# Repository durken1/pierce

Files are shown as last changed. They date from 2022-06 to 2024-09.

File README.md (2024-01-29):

# pierce 2.0

pierce  

pierce 2.0 is a split modular wireless / semi-wireless 36 key column staggered keyboard. The design is inspired by [Corne](https://github.com/foostan/crkbd) with more pinky stagger as well as only using 1u keycaps.
It is possible to build a wireless version or a semi wireless version. If building the wireless version an additional reciever dongle is required. 
In the semi wireless version the wired half is also acting as a reciever for the wireless half.
Both versions have full [QMK support](https://github.com/qmk/qmk_firmware/tree/master/keyboards/pierce).  
Supported switches: MX, Choc V1, Alps

The semi wireless version has a built in reset circuit for connecting a PS/2 pointing device.

There are 3 different PCBs: wireless (reversible), wired (right) and reciever.

A programmer is necessary to flash the wireless modules. A cheap option is getting an ST-Link V2 clone from ebay.

# Bill of materials
## Wireless
| Qty | Item | Comments |
|----:|---|---|
| 2 | Pierce 2.0 wireless PCB | |
| 1 | Pierce 2.0 reciever PCB | |
| 1 | Pro micro or equivalent | |
| 2 | Keystone 3034 Coin cell battery retainer | SMD |
| 2 | 2032 3.3V Coin cell battery | |
| 3 | YJ-14015 / Core51822 (B) | |
| 3 | 1x4 pin Right-angle 2.54 mm header | For programming RF modulules. Optional, temporary soldered wires works fine|
| 2 | 4.7 kΩ resistor | SMD 1206 |
| 1 | 1117 3.3 V regulator | SMD SOT-223 |
| 1 | THT momentary switch | 2 pin THT 6 mm |
  
## Semi wireless
| Qty | Item | Comments |
|----:|---|---|
| 1 | Pierce 2.0 wireless PCB | |
| 1 | Pierce 2.0 wired PCB | |
| 1 | Pro micro or equivalent | Elite C recommended if using trackpoint. (Pin D5 broken out)|
| 1 | Keystone 3034 Coin cell battery retainer | SMD |
| 1 | 2032 3.3V Coin cell battery | |
| 2 | YJ-14015 / Core51822 (B) | |
| 2 | 1x4 pin Right-angle 2.54 mm header | For programming RF modulules. Optional, temporary soldered wires works fine|
| 2/4 | 4.7 kΩ resistor | SMD 1206, 4 if using trackpoint, otherwise 2 |
| 1 | 1117 3.3 V regulator | SMD SOT-223 |
| 1 | THT momentary switch | 2 pin THT 6 mm |
| 1 | 100 kΩ resistor | SMD 1206 Only for trackpoint |
| 1 | 2.2 uF capacitor | SMD 1206 Only for trackpoint |
| 1 | Trackpoint module | [R61](https://deskthority.net/wiki/TrackPoint_Hardware#ThinkPad_R61_TrackPoint) recommended, Only for.. well..|
  
# Build instructions
## Soldering

The soldering is pretty straight forward and it should be obvious what component goes where. If you haven't soldered SMD components before I recommend watching a youtube tutorial or two beforehand. I suggest adding a bit of solder to the middle pad for the battery holder.

## Flashing wireless modules

The following instructions is for using an ST-Link V2 clone and Windows.
1. Download and install OpenOCD from https://openocd.org/ and drivers for the programmer from https://www.st.com/en/development-tools/stsw-link009.html
2. Create a file called 'openocd.cfg' in the bin folder where you installed OpenOCD with the following content:

        #nRF51822 Target
        source [find interface/stlink-v2.cfg]

        transport select hla_swd

        set WORKAREASIZE 0x4000
        source [find target/nrf51.cfg]

3. Copy the relevant firmware .bin file to the bin folder where you installed OpenOCD
4. Connect the 4 pins SWCLK, SWDIO, GND and 3.3 V on the ST-Link V2 to the matching pad on the PCB and the ST-Link to the computer
5. Open a command prompt, navigate to the bin folder mentioned above and enter:

        openocd.exe -f openocd.cfg
        
6. Open another command prompt and enter:

        telnet localhost 4444
You should now be connected to the programmer. Enter the following commands to flash the firmware:

    halt
    nrf51 mass_erase
    program <firmware_file_name>.bin
    reset

That's it! You should now have a working pierce keyboard.

# Plates
## These need some work
I have included files to 3D print bottom plates and switch plates (only for alps for now). The idea of the screwless bottom plates is to use a friction fit, but I'm not sure how well the current version fits.

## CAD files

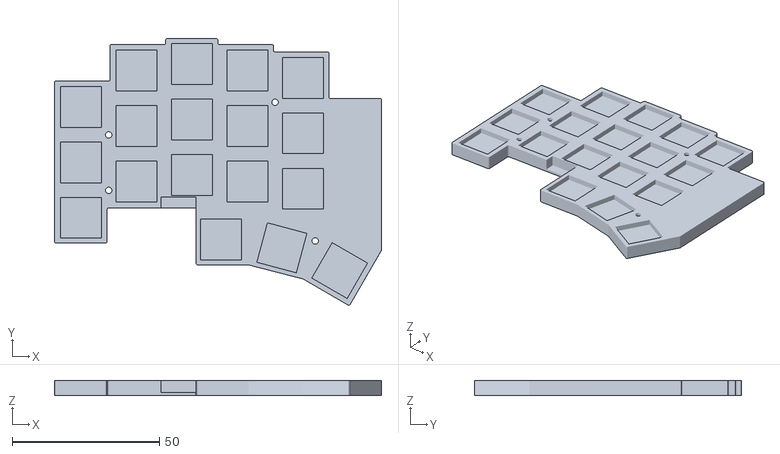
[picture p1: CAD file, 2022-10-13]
plates/Pierce MX Bottom Plate.stl
111.2 x 90.6 x 5.00

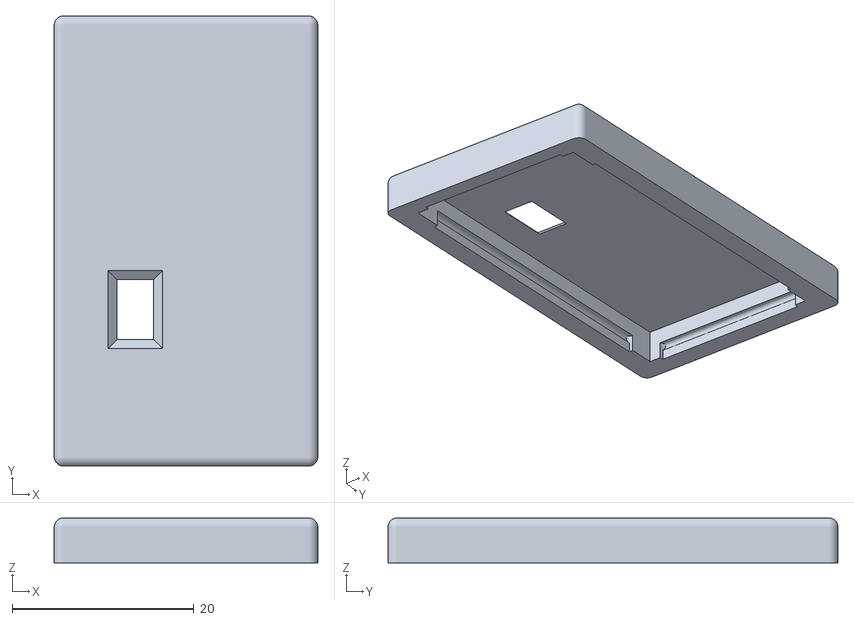
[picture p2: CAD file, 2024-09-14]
receiver_box/receiver_top.stl
29.0 x 49.5 x 4.95

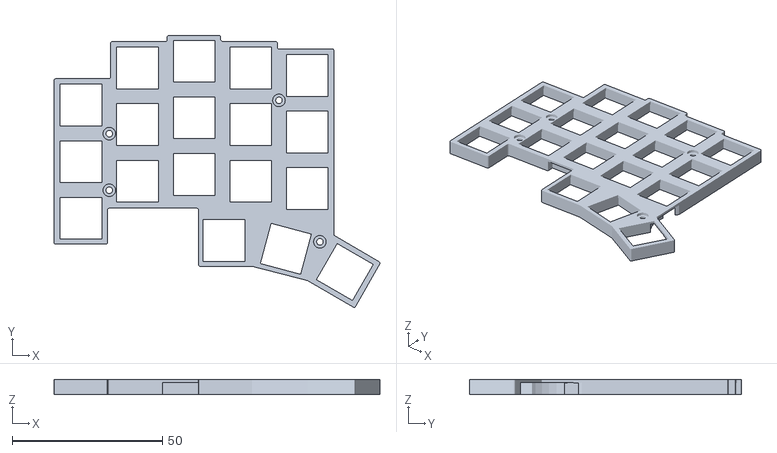
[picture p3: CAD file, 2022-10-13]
plates/Pierce MX Top Plate.stl
108.7 x 90.6 x 5.00

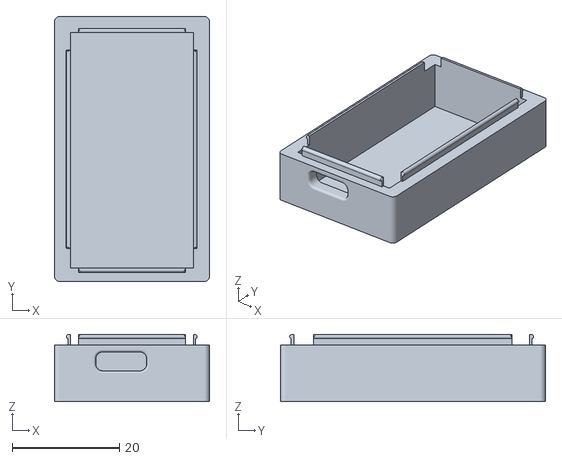
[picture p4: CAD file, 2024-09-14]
receiver_box/receiver_bottom.stl
29.0 x 49.5 x 12.6

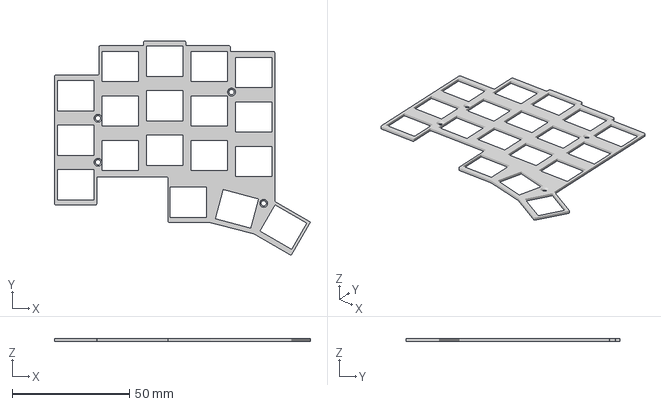
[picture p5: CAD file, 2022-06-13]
plates/alps_plate.3mf
109.3 x 91.4 x 1.20 mm

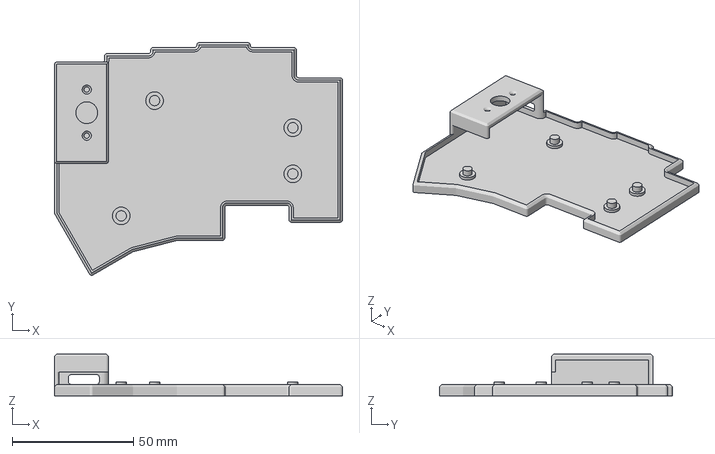
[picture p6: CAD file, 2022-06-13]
plates/wired_trackpoint_screwless.3mf
118.7 x 95.9 x 17.3 mm

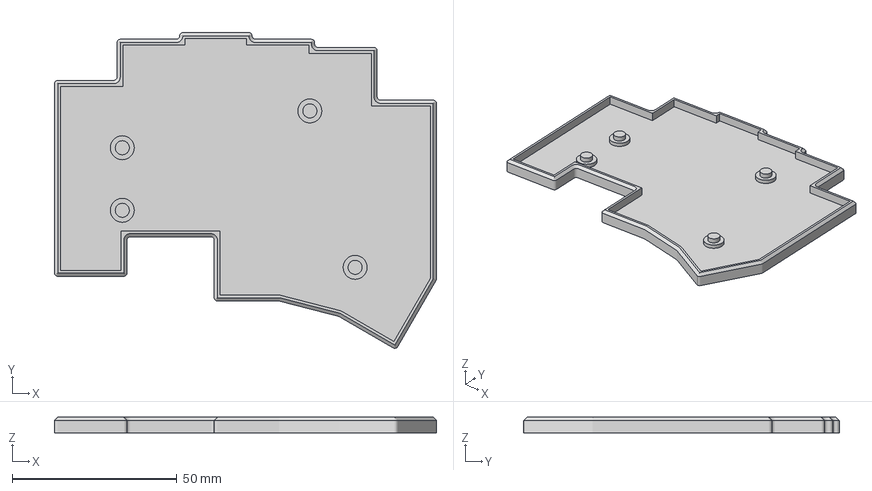
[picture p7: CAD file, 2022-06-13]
plates/wireless_bottom_screwless.3mf
116.0 x 95.9 x 4.80 mm

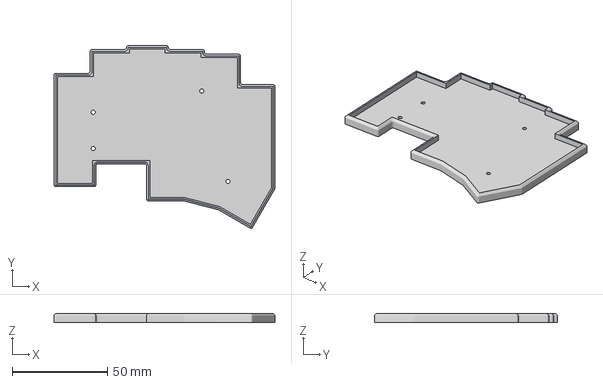
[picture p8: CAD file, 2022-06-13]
plates/wireless_bottom_screws.3mf
116.0 x 95.9 x 4.80 mm

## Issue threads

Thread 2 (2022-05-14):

Hello, good fellow.

azhizhinov, 2022-05-14:
Hello, good fellow.
Very interesting project.
Are these samples are completely functional?
Don't you mind if I've try to solder fully wireless one with dongle?
Thanks for your efforts.

durken1, 2022-05-14:
Hello,
You're very welcome to build it!
Everything is fully functional (I'm using this version as my daily driver).
I have a pending PR to the qmk main repo, but until it's approved you can get it here: https://github.com/durken1/qmk_firmware/tree/pierce/keyboards/pierce

azhizhinov, 2022-05-15:
Hello.
It seems, that you uses different case model for pierce 2.0.
Old cases looks too high.
Do you have some plans to release new case models?
Thanks in advance.

durken1, 2022-05-15:
Yes, that's true, the old case won't fit. I have made some simple bottom plates that I use. I'll add the STLs when I get the chance.

durken1, 2022-05-21:
Nice, if you decide to try them let me know how they work and I can add them to the repo.
I added the plates that I use. The screwless uses friction fit to attach the pcbs for a plateless build. The margins at the mounting points are quite small, so dependig on the printer it migh work better or worse.

azhizhinov, 2022-05-21:
Hello.
Thanks a lot.
For how long CR2032 will provide enough power for a half with daily usage?
At what distance from the halves does the receiver still provide stable communication?

durken1, 2022-05-21:
It's a bit difficult to say. They should last for almost 1000 hours of active typing and with current firmware they go to deep sleep after 0.5 seconds. So it kinda depends on how much you type during daily usage. But to give an estimate, I used the prototype for about 9 months before having to change the battery.

I have tried them from about 3 meters away and through a door without issue. I can do some more testing to find out how far before they fail if you're interested.

azhizhinov, 2022-05-21:
Cool. This information is enough for.
Good results.

azhizhinov, 2022-05-23:
Hello.
Please, advice, how can I mirror wireless_bottom_screwless.3mf?
It's for left the half, right?
How the same model can be printed for the left half?
A 3D printer can mange such situation?
Thanks in advance.

durken1, 2022-05-23:
Yes, it's the left half. It can easily be mirrored in the slicing software before printing.

azhizhinov, 2022-05-23:
Is it not planned to use the top plate for Cherries, as for Alps?
Are the Cherries stable enough without the top plate?

durken1, 2022-05-23:
I will make a top plate for MX switches as well. At the moment I don't have much time though, but it's coming :). If the switches are 5 pin you don't have to have a top plate. If they are 3 pin you need a plate. You can see the difference here: https://m.media-amazon.com/images/I/61kURKmWOvL._AC_SL400_.jpg

azhizhinov, 2022-05-23:
Yep, time is always passing by.
Ok, I see, mine are 3-pin.
I think alps_plate.3mf can be used as well.
The Alps are for 15x14 mm cuts, the Cherries are for 14x14 cuts, centers of switches are the same, I think.
But borders of the bottom plate should be higher then, to hide the PCB itself and the top plate under.

azhizhinov, 2022-06-12:
Hello.
Do you have the case parts in .STL format?
It's more comfortable for editing with some free tools like FreeCAD.
Will be great to adopt this kind of bottom plate to Pierce, how do you think?
https://github.com/mattdibi/redox-keyboard/blob/master/redox-w/rev2.0WHS/case/BackplateL.stl
https://github.com/mattdibi/redox-keyboard/blob/master/redox-w/rev2.0WHS/case/OpenBackplateL.stl

durken1, 2022-06-14:
Hi!

I can export the case parts to STL when I get home from work today.
Regarding the other type of bottom plates, that's not really something I would find useful, but if you want to make them I'm happy to include them in the repo.

azhizhinov, 2022-06-19:
Hello.
There is some automation for cases.
May be you'll find this interesting.
https://github.com/Lenbok/scad-keyboard-cases

azhizhinov, 2022-06-29:
Hello.
An idea for the case, maybe that style already used in some projects, I don't know.
To fasten the switch plate with the bottom plate through the PCB.
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

durken1, 2022-06-30:
Hello.
You can find the hole on the pcb using kicad (pcbnew).
Regarding the mounting I guess it should work, but personally i prefer solutions that you can disassemble more easily. But let me know if you try it out and how it works!

And nice to see you flashed the dongle successfully :) please keep me updated on your build.

azhizhinov, 2022-06-30:
Hello.
Yep, I get to this point with the same conclusion. It's better to have possibility to disassemble a keyboard.
I've studied a lot of videos and now have better understanding of  KiCAD -> Blender process.
Sure will update, next step is to solder one of the halves and test with dongle.

azhizhinov, 2022-07-02:
Hello.
That was my first challenge with Blender.
So, here the result.
Could you, please check?
Do you have possibility to print these plates?
[20220702.DURKEN1.PIERCE.00.zip](https://github.com/durken1/pierce/files/9033579/20220702.DURKEN1.PIERCE.00.zip)

azhizhinov, 2022-08-21:
Hello.
I'm finished.
Now time for keymap/layers. :-)
Have you any plans for VIA/VIAL support?
Thanks in advance.
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

durken1, 2022-08-22:
Looks good! How do you like it?

No plans for via/vial support at the moment. Feel free to add it and make a PR though :)

durken1, 2022-09-06:
Are the plates working as intended? If so, would you mind adding them to the plates-folder with a PR? :)

azhizhinov, 2022-10-03:
> Are the plates working as intended? If so, would you mind adding them to the plates-folder with a PR? :)

Hello.
I've made the PR for plates.
And for via support also.
Have a nice day.

azhizhinov, 2023-03-24:
Hello.
Pierce now has support from VIA.
https://github.com/the-via/keyboards/pull/1747
Stay safe.

durken1, 2023-03-24:
Hello,
Nice! Thank you for your contribution!

Closed 2023-01-06.

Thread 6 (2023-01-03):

Flesh out build guide

chewiedies, 2023-01-03:
I am having a lot of trouble flashing the wireless modules. The instructions in the build guide are quite sparse and seem to make a lot of assumptions. Can you write up a more robust build guide with regards to firmware flashing and wireless module flashing?

azhizhinov, 2023-01-03:
Hello.
Sorry for shameless intervene.
I've flashed at least 12 modules.
It's easy with ST-Link and openocd.
Just need a Linux installation with openocd.
You have to connect a wireless module with a ST-Link programmer.
Create nameitasyouwant.cfg with the following:
```
#nRF51822 Target
source [find interface/stlink.cfg]
transport select hla_swd
set WORKAREASIZE 0x4000
source [find target/nrf51.cfg]
```

Start the openocd process with `openocd -f nameitasyouwant.cfg`.

Connect to the openocd server with `telnet localhost 4444` and issue these commands:
```
halt
nrf51 mass_erase
program <full path to firmware>.bin
reset
```
The firmware for [dongle](https://github.com/durken1/pierce/blob/master/wireless_modules_firmware/dongle/bin/pierce_dongle.bin).
The firmware for the [left controller](https://github.com/durken1/pierce/blob/master/wireless_modules_firmware/wireless/bin/left/pierce_wireless_left.bin).
The firmware fore the [right controller](https://github.com/durken1/pierce/blob/master/wireless_modules_firmware/wireless/bin/right/pierce_wireless_right.bin).
Thats it.

azhizhinov, 2023-01-03:
Basically it's the same process as described [here](https://github.com/mattdibi/redox-keyboard/tree/master/redox-w#firmware) for Redox.

chewiedies, 2023-01-03:
I actually got it working after I submitted this issue. I used this guide to get it all working: https://docs.beekeeb.com/other-guides/how-to-flash-a-firmware-with-openocd. After I had OpenOCD and MSYS2 installed it all started to make more sense.  I also had a different programmer which required a different interface config. Once I figured out my issues and how my setup differed slightly from the build guide it all went smoothly.

azhizhinov, 2023-01-05:
Hello. @chewiedies
Nice [build](https://www.reddit.com/r/ErgoMechKeyboards/comments/103fknc/my_first_5col_pierce_wireless_running_qmk/).
Will you share the case? :-)

chewiedies, 2023-01-05:
> Hello. @chewiedies Nice [build](https://www.reddit.com/r/ErgoMechKeyboards/comments/103fknc/my_first_5col_pierce_wireless_running_qmk/). Will you share the case? :-)

@azhizhinov I am still revising the design after the first print. I'm nearly done and will upload it here once I finish. https://www.printables.com/social/360738-chewiedies/models

durken1, 2023-01-05:
Glad you got it working! And really nice build, hope you like it :)

Closed 2023-01-06.

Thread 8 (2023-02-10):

Choc V1 compatibility

ruehri, 2023-02-10:
Hey I saw the layout should be compatible with choc V1 sockets. Normally you would solder the socket on the bottom of the key, but in the layout here all pin holes seem to be on the top. Do I understand it correctly that choc V1 sockets and switches would be soldered/attached upside down?

durken1, 2023-02-11:
Hi,

It doesn't support any sockets, only switches soldered directly to the PCB

ruehri, 2023-02-11:
Ah got it, thanks a lot for the clarification!

Closed 2023-02-11.

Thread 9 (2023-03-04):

build problem in mac

Biisairo, 2023-03-04:
I'm almost done with my project and have a question.
I have two issues.
First. When I power on and connect, the left side connects immediately, while the right side either doesn't connect or takes a long time to connect.
Second. When the distance from the transmitter is more than 5cm, it doesn't connect properly.

Additionally, I don't have a Windows PC, so I used brew on my Mac to install openocd and stlink.

durken1, 2023-03-05:
Not sure what could cause those problems to be honest, I haven't had any issues like that in any of my builds. I have tested the connection up to about 5 m away and through a door without problems.

There is an option to define what channels to use for the wireless connection, and using interleaved channels for the left and right modules should improve stability in theory, but I never got around to implementing it since it worked fine for me, but that might be something worth checking out. Just let me know if you need any help with that.

Faulty hardware is of course also possible, do you have additional modules you could try?

Biisairo, 2023-03-17:
I apologize for not replying for so long.

I tried creating a new receiver, but the situation is the same.
If it's a problem with the transmitter (keyboard), I can't create one right now, so I'm not sure yet.
My friend who is building it with me says he's still working on it, so I'll wait and see.

Additionally,
Have you tried flashing the firmware using macos?
I used brew to install openocd and telnet and then flashed it.
I'm not sure if it's my device or the flash process that's the problem.
If you have a macos machine, could you please test the firmware flash with macos?

Biisairo, 2023-03-18:
Hold on a second
Looking at the PCB, it looks like there is no ground under the antenna part of the wireless module.
If there is a ground under the antenna, will this cause a weak signal and prevent it from connecting properly?

The reason I ask this question is because I made a little modification to the PCB

durken1, 2023-03-18:
Yes, a ground plane under the antenna would weaken the signal.

Regarding macOS I dont have access to a Mac, so I cant test that.

Have you double checked all the soldier joints for the wireless modules on the keyboard? Preferably with a multimeter to be sure there are no shorts.

Biisairo, 2023-03-19:
The keyboard I made worked with a very weak signal at very close range.
I think it's probably the ground under the antenna I mentioned above.
My partner says he can fix the board and send it to me in a month or two, so I'll try to build it again and let you know.
Thanks a lot for the reply.

durken1, 2023-03-27:
Alright. I'll close this issue then.
Let me know if you need anything else!

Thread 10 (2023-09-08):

To use RP2040-Zero instead of ProMicro...

azhizhinov, 2023-09-08:
Hello, good fellow.
Can I borrow your attention one more time?
How do you think, is it possible?
Thanks in advance.
[20230908.DURKEN1.PIERCE-RECEVIER.00.pdf](https://github.com/durken1/pierce/files/12559201/20230908.DURKEN1.PIERCE-RECEVIER.00.pdf)

azhizhinov, 2023-09-15:
Hello.
It can be done in this way.
Need some help here.
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

durken1, 2023-10-13:
Hello! Sorry for the late reply.
Did you get any further with this? I would assume the voltage regulator is not needed since the rp2040 runs on 3.3 V and the zero already has a regulator.

azhizhinov, 2023-10-13:
Hello.
Thanks for your answer.
I made the same assumption, but was not sure enough.

azhizhinov, 2023-10-16:
Can't stop this. :-)
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
[20231016.PIERCE-RECEIVER-COMBO.00.zip](https://github.com/durken1/pierce/files/12914579/20231016.PIERCE-RECEIVER-COMBO.00.zip)

weekinro, 2024-07-25:
你好，这太棒了，请问有代码吗

Closed 2024-01-29.

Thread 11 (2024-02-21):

Receiver box case

tokyo2006, 2024-02-21:
This is a cool mechanical keyboard. I followed your guide and assembled it.
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
But I didn't find a receiver box case, so I created it, and I attached this here
[receiver_box_case.zip](https://github.com/durken1/pierce/files/14354507/receiver_box_case.zip)

durken1, 2024-02-21:
Thank you!
Can I add the STLs to the repo? If you want you can add them yourself and do a PR or I can just add them and give you credit.

Closed 2024-09-14.

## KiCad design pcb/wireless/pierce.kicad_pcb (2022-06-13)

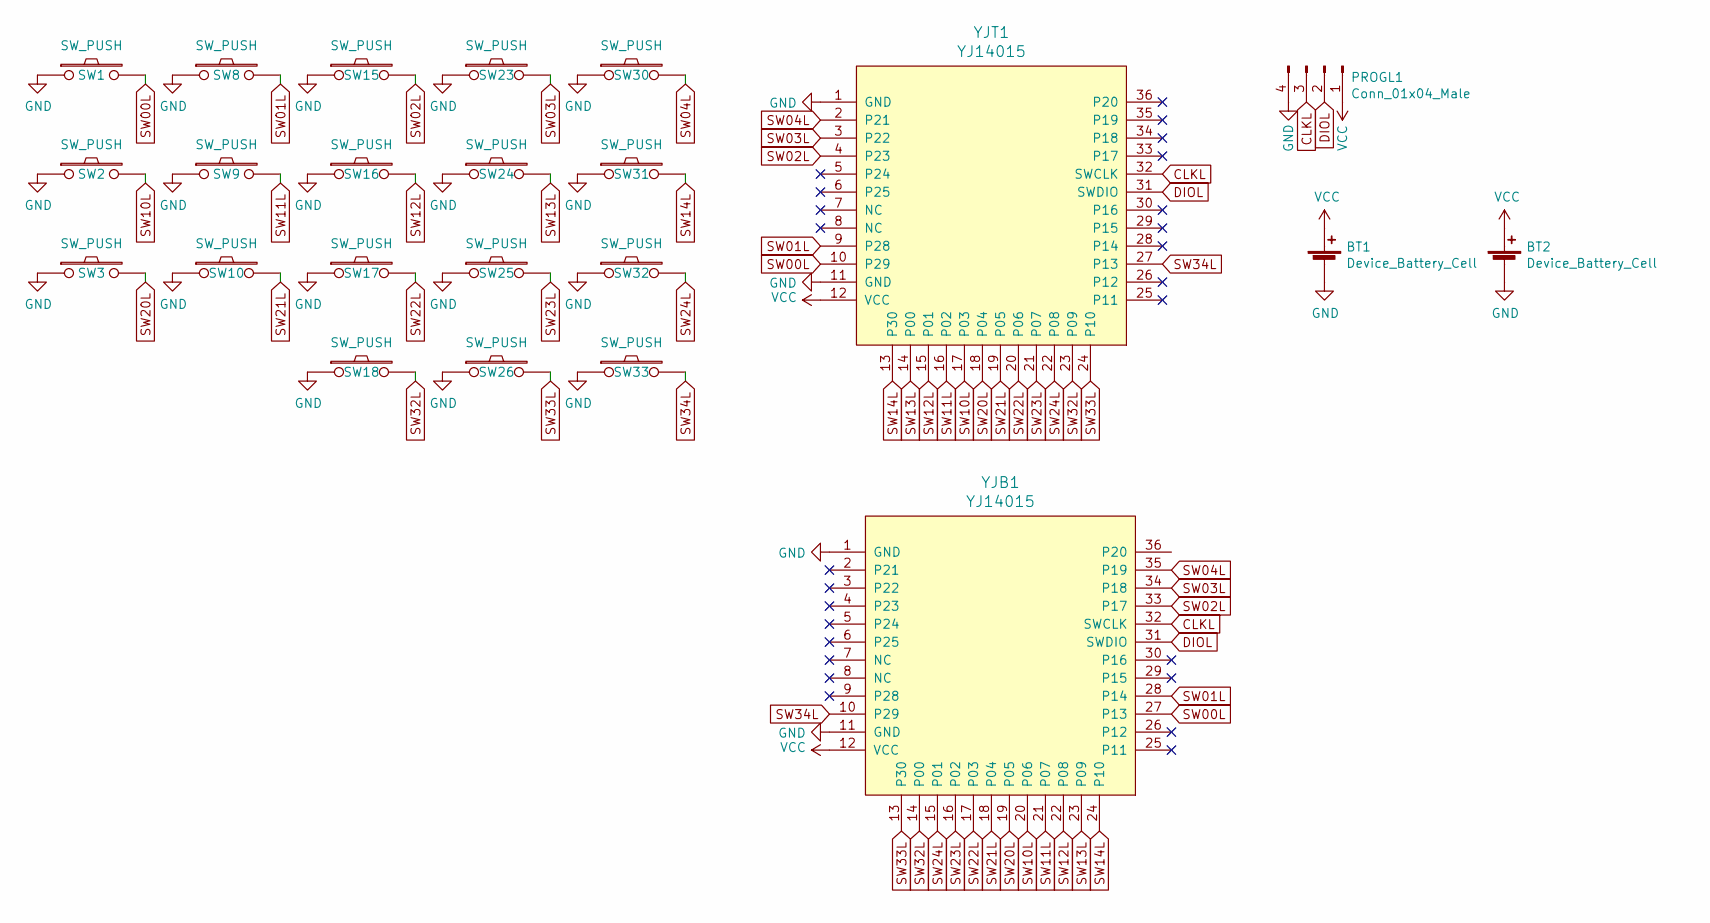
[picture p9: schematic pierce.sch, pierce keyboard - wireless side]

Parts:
BT1, BT2: Device_Battery_Cell; BatteryHolder_Keystone_3034_1x20mm
PROGL1: Conn_01x04_Male; PinHeader_1x04_P2.54mm_Horizontal
SW1, SW2, SW3, SW8, SW9, SW10, SW15, SW16, SW17, SW18, SW23, SW24, SW25, SW26, SW30, SW31, SW32, SW33: SW_PUSH; MX_ALPS_PG1350_noLed
YJB1: YJ14015; YJ-14015
YJT1: YJ14015; YJ-14015

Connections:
CLKL: PROGL1.3, YJB1.32 (SWCLK), YJT1.32 (SWCLK)
DIOL: PROGL1.2, YJB1.31 (SWDIO), YJT1.31 (SWDIO)
GND: BT1.2 (-), BT2.2 (-), PROGL1.4, SW1.1, SW2.1, SW3.1, SW8.1, SW9.1, SW10.1, SW15.1, SW16.1, SW17.1, SW18.1, SW23.1, SW24.1, SW25.1, SW26.1, SW30.1, SW31.1, SW32.1, SW33.1, YJB1.1 (GND), YJB1.11 (GND), YJT1.1 (GND), YJT1.11 (GND)
SW00L: SW1.2, YJB1.27 (P13), YJT1.10 (P29)
SW01L: SW8.2, YJB1.28 (P14), YJT1.9 (P28)
SW02L: SW15.2, YJB1.33 (P17), YJT1.4 (P23)
SW03L: SW23.2, YJB1.34 (P18), YJT1.3 (P22)
SW04L: SW30.2, YJB1.35 (P19), YJT1.2 (P21)
SW10L: SW2.2, YJB1.20 (P06), YJT1.17 (P03)
SW11L: SW9.2, YJB1.21 (P07), YJT1.16 (P02)
SW12L: SW16.2, YJB1.22 (P08), YJT1.15 (P01)
SW13L: SW24.2, YJB1.23 (P09), YJT1.14 (P00)
SW14L: SW31.2, YJB1.24 (P10), YJT1.13 (P30)
SW20L: SW3.2, YJB1.19 (P05), YJT1.18 (P04)
SW21L: SW10.2, YJB1.18 (P04), YJT1.19 (P05)
SW22L: SW17.2, YJB1.17 (P03), YJT1.20 (P06)
SW23L: SW25.2, YJB1.16 (P02), YJT1.21 (P07)
SW24L: SW32.2, YJB1.15 (P01), YJT1.22 (P08)
SW32L: SW18.2, YJB1.14 (P00), YJT1.23 (P09)
SW33L: SW26.2, YJB1.13 (P30), YJT1.24 (P10)
SW34L: SW33.2, YJB1.10 (P29), YJT1.27 (P13)
VCC: BT1.1 (+), BT2.1 (+), PROGL1.1, YJB1.12 (VCC), YJT1.12 (VCC)

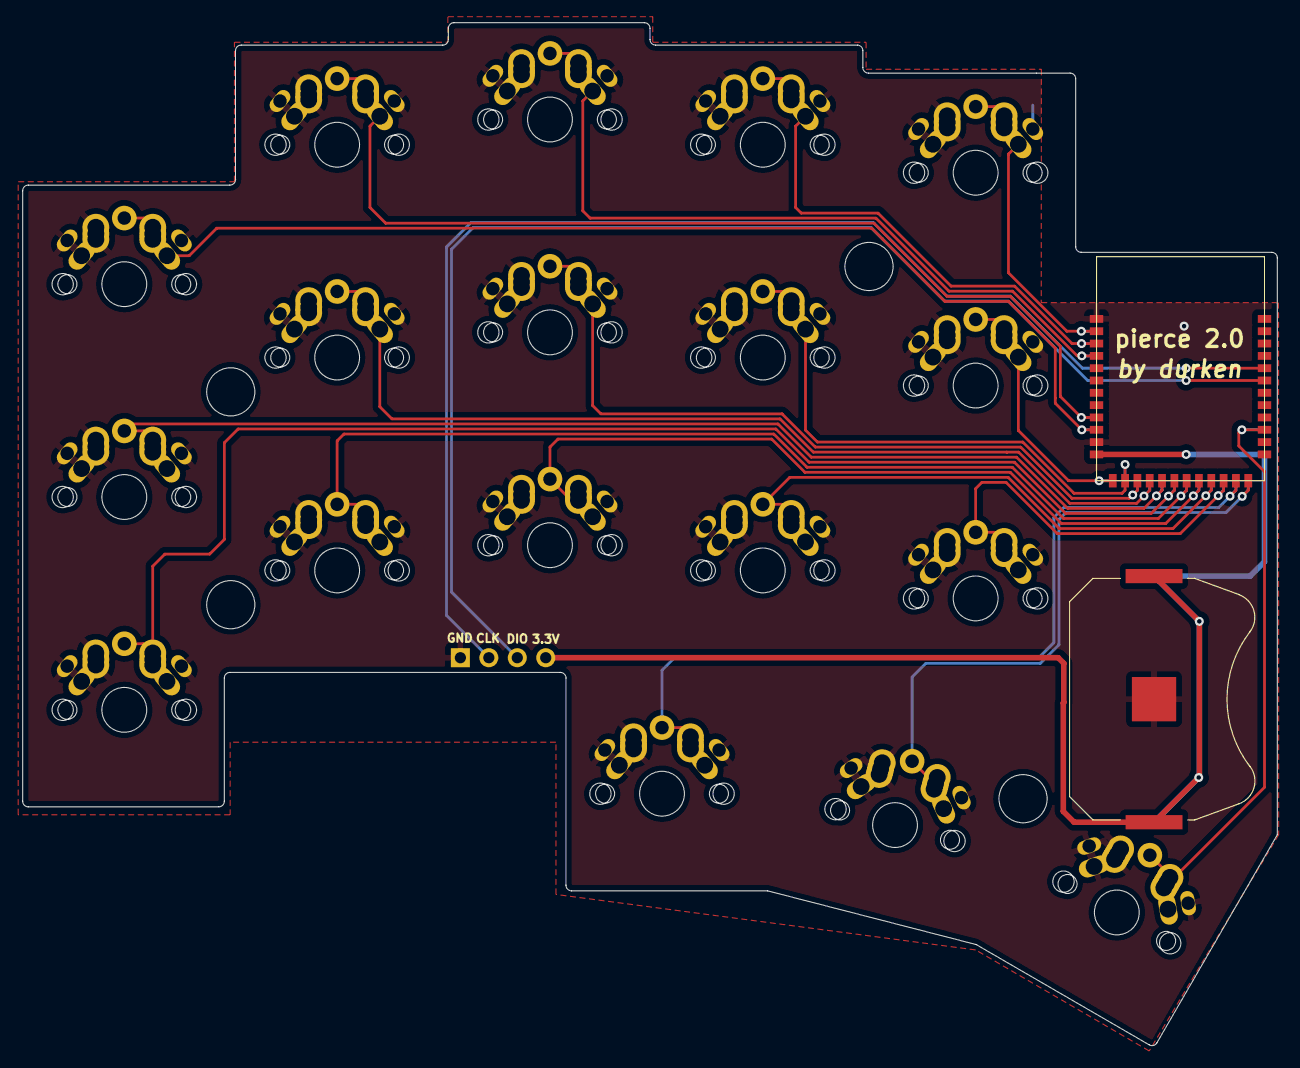
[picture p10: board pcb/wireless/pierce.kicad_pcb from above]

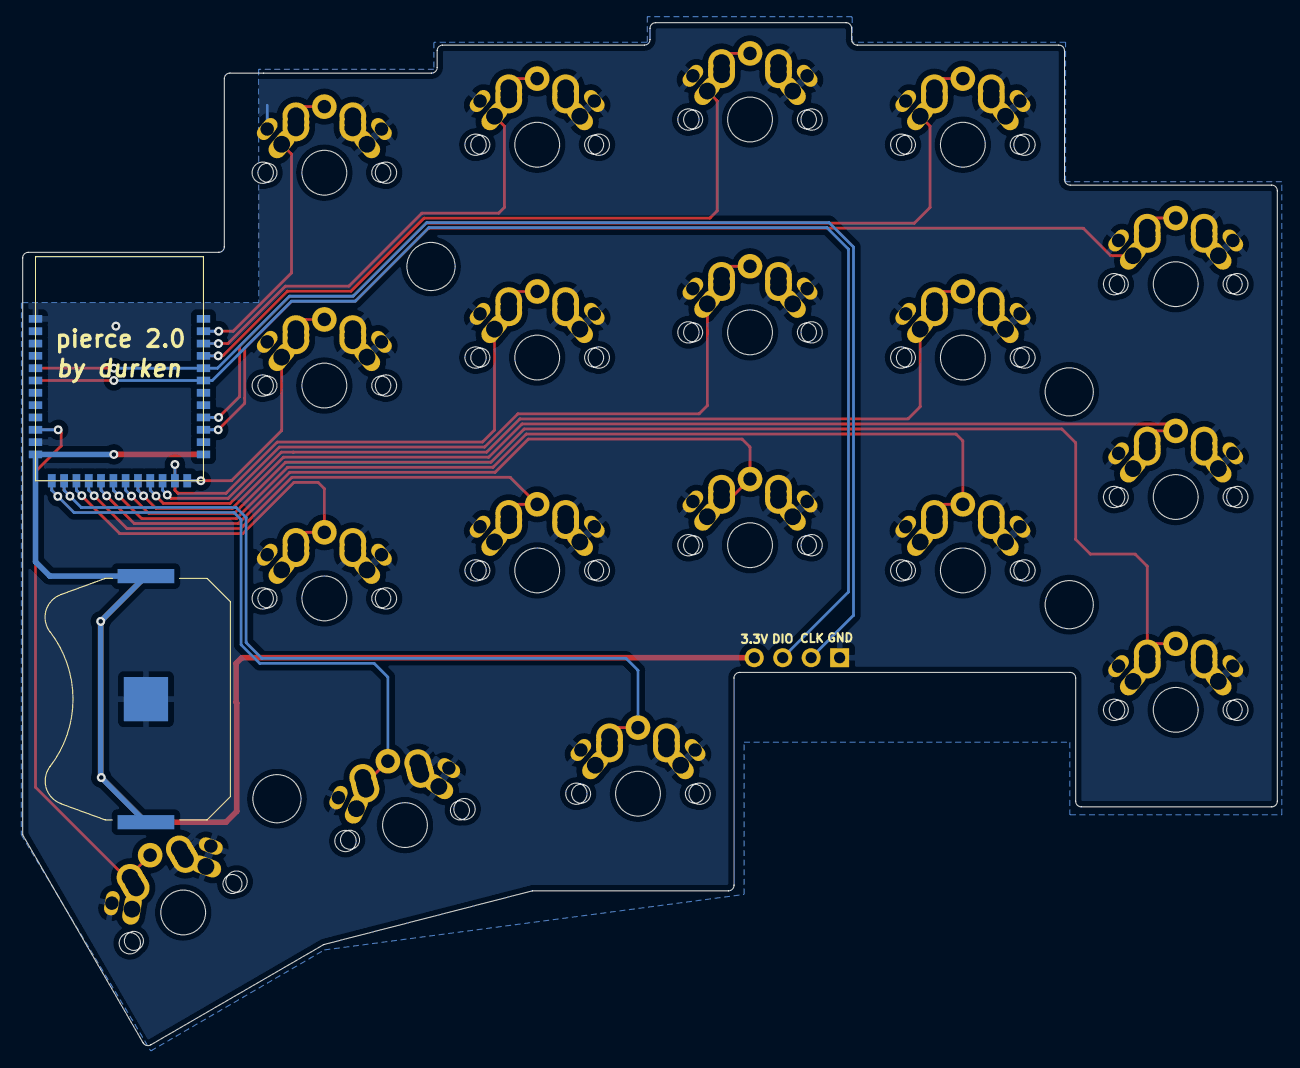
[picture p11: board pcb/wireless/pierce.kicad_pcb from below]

Board: 2 copper layers, 112.0 x 91.3 mm, 27 parts (2 on the bottom side), 22 nets.

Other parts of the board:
Ref**: Val**; M2_HOLE_v2
Ref**#2, Ref**#3, Ref**#4: Val**; M2_HOLE_v2

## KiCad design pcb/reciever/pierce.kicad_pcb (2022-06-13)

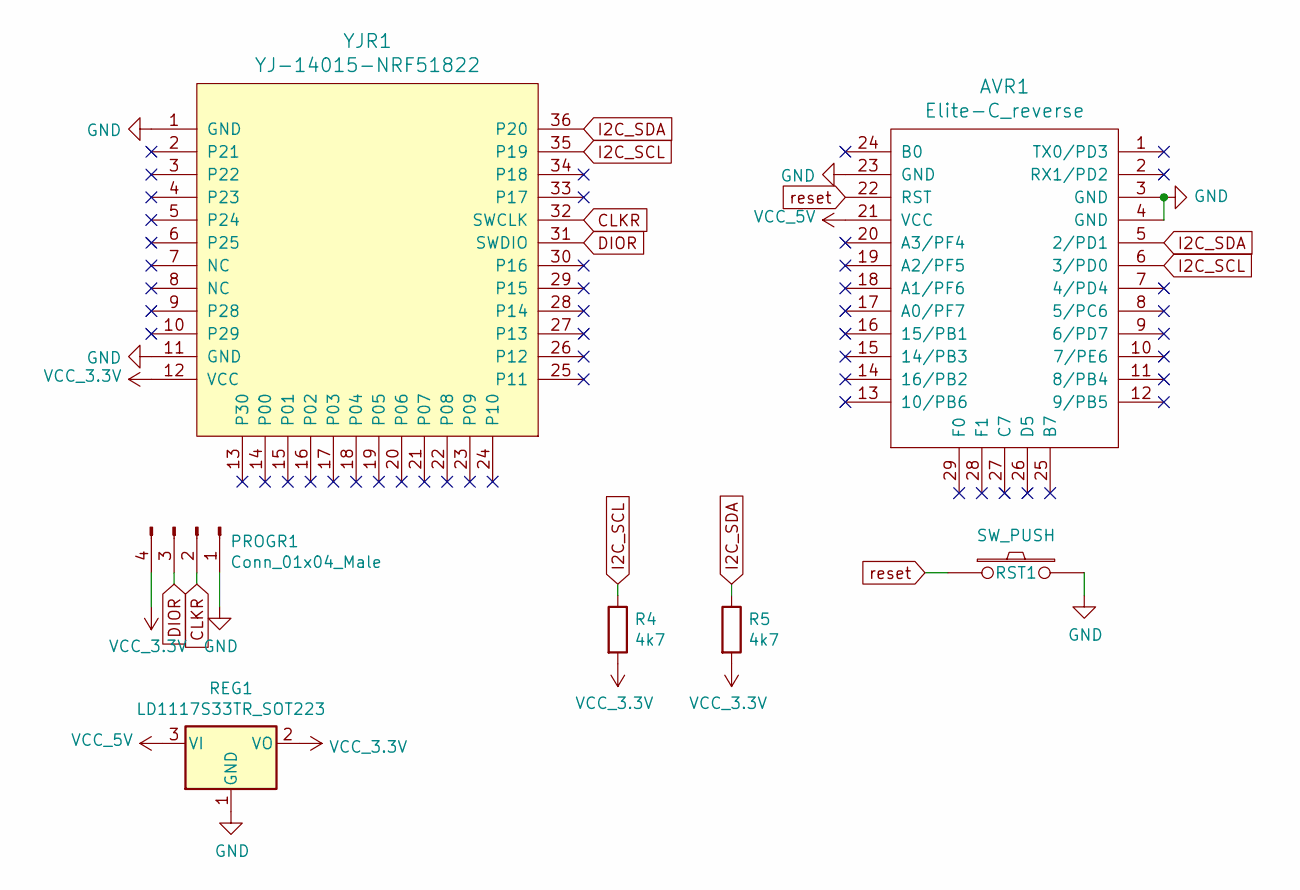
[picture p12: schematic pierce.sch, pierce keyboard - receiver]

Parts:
AVR1: Elite-C_reverse; Elite-C_reverse_I2C
PROGR1: Conn_01x04_Male; PinHeader_1x04_P2.54mm_Vertical
R4, R5: 4k7; R_SMD_v2
REG1: LD1117S33TR_SOT223; SOT-223-3_TabPin2
RST1: SW_PUSH; ResetSW_1side
YJR1: YJ-14015-NRF51822; YJ-14015

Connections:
CLKR: PROGR1.2, YJR1.32 (SWCLK)
DIOR: PROGR1.3, YJR1.31 (SWDIO)
GND: AVR1.3 (GND), AVR1.4 (GND), AVR1.23 (GND), PROGR1.1, REG1.1 (GND), RST1.2, YJR1.1 (GND), YJR1.11 (GND)
I2C_SCL: AVR1.6 (3/PD0), R4.1, YJR1.35 (P19)
I2C_SDA: AVR1.5 (2/PD1), R5.1, YJR1.36 (P20)
VCC_3.3V: PROGR1.4, R4.2, R5.2, REG1.2 (VO), YJR1.12 (VCC)
VCC_5V: AVR1.21 (VCC), REG1.3 (VI)
reset: AVR1.22 (RST), RST1.1

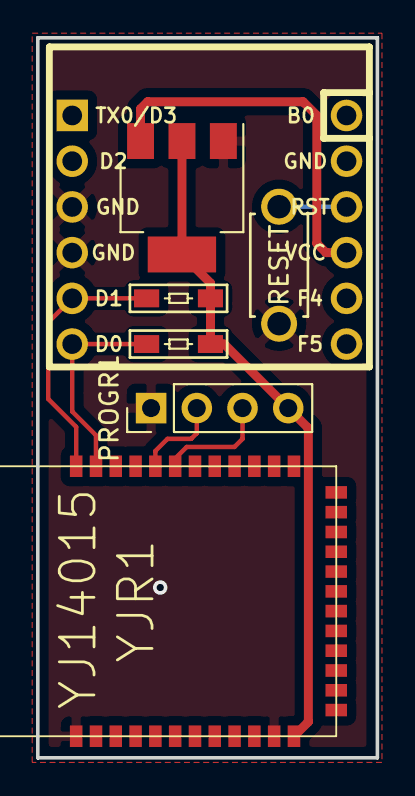
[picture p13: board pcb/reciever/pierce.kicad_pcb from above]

Board: 2 copper layers, 18.9 x 40.0 mm, 7 parts (1 on the bottom side), 8 nets.

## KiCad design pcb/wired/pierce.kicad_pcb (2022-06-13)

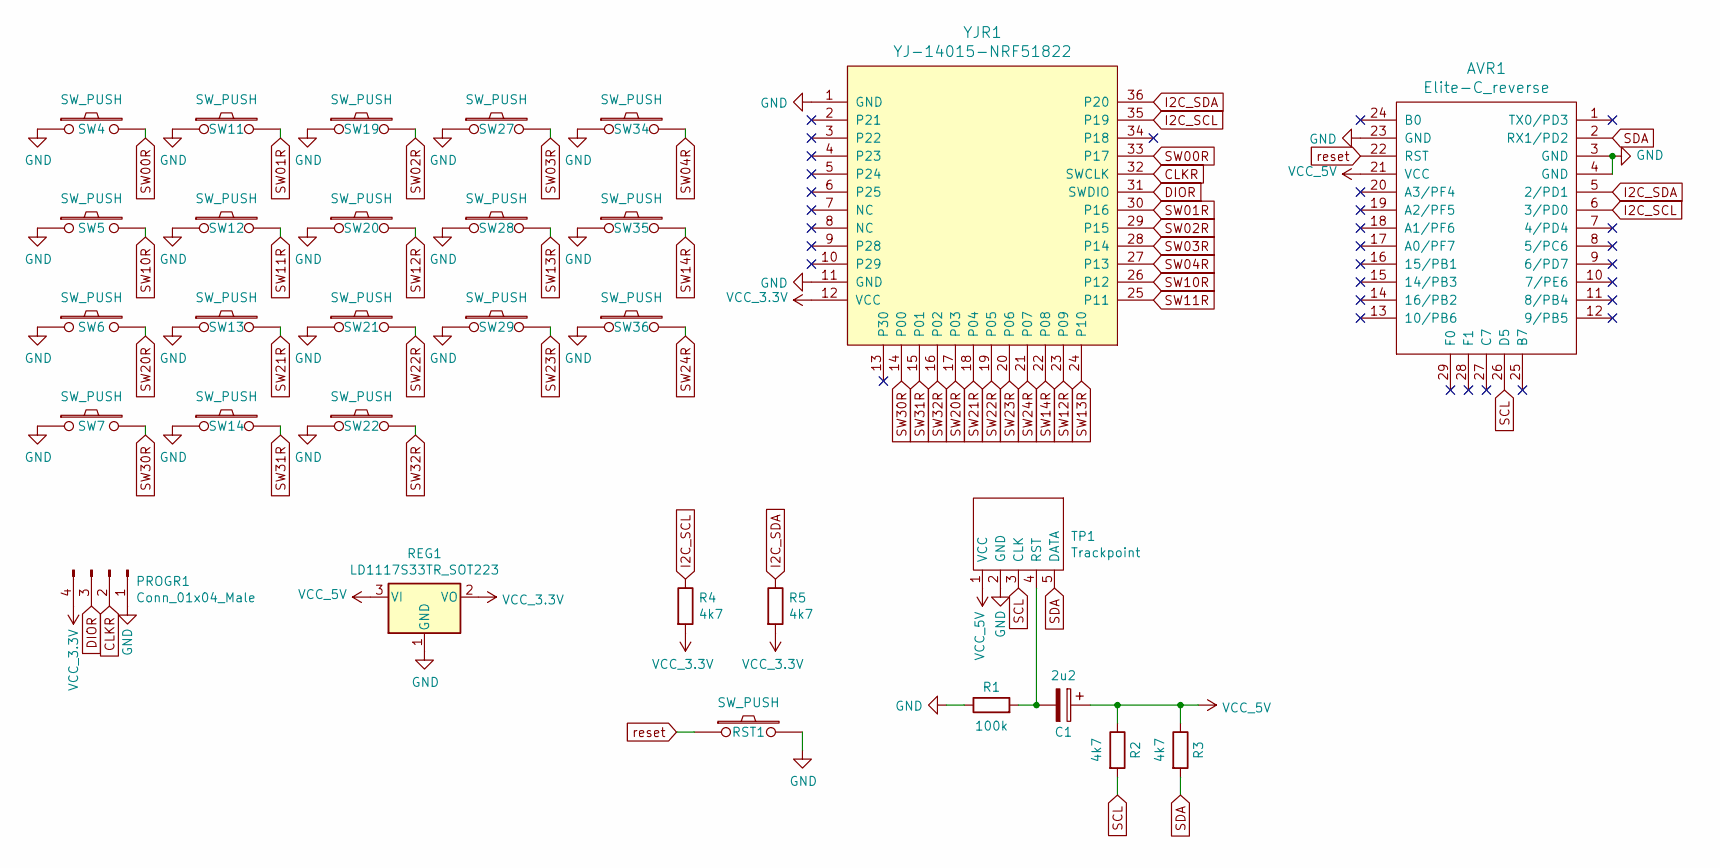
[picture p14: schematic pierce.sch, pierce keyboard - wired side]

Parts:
AVR1: Elite-C_reverse; Elite-C_reverse_D5
C1: 2u2; C_SMD_v2
PROGR1: Conn_01x04_Male; PinHeader_1x04_P2.54mm_Horizontal
R1: 100k; R_SMD_v2
R2, R3, R4, R5: 4k7; R_SMD_v2
REG1: LD1117S33TR_SOT223; SOT-223-3_TabPin2
RST1: SW_PUSH; ResetSW_1side
SW4, SW5, SW6, SW7, SW11, SW12, SW13, SW14, SW19, SW20, SW21, SW22, SW27, SW28, SW29, SW34, SW35, SW36: SW_PUSH; CherryMX_ChocV2_1u
TP1: Trackpoint; TRACKPOINT
YJR1: YJ-14015-NRF51822; YJ-14015

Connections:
CLKR: PROGR1.2, YJR1.32 (SWCLK)
DIOR: PROGR1.3, YJR1.31 (SWDIO)
GND: AVR1.3 (GND), AVR1.4 (GND), AVR1.23 (GND), PROGR1.1, R1.1, REG1.1 (GND), RST1.2, SW4.1, SW5.1, SW6.1, SW7.1, SW11.1, SW12.1, SW13.1, SW14.1, SW19.1, SW20.1, SW21.1, SW22.1, SW27.1, SW28.1, SW29.1, SW34.1, SW35.1, SW36.1, TP1.2 (GND), YJR1.1 (GND), YJR1.11 (GND)
I2C_SCL: AVR1.6 (3/PD0), R4.1, YJR1.35 (P19)
I2C_SDA: AVR1.5 (2/PD1), R5.1, YJR1.36 (P20)
unnamed: C1.2, R1.2, TP1.4 (RST)
SCL: AVR1.26 (D5), R2.2, TP1.3 (CLK)
SDA: AVR1.2 (RX1/PD2), R3.2, TP1.5 (DATA)
SW00R: SW4.2, YJR1.33 (P17)
SW01R: SW11.2, YJR1.30 (P16)
SW02R: SW19.2, YJR1.29 (P15)
SW03R: SW27.2, YJR1.28 (P14)
SW04R: SW34.2, YJR1.27 (P13)
SW10R: SW5.2, YJR1.26 (P12)
SW11R: SW12.2, YJR1.25 (P11)
SW12R: SW20.2, YJR1.23 (P09)
SW13R: SW28.2, YJR1.24 (P10)
SW14R: SW35.2, YJR1.22 (P08)
SW20R: SW6.2, YJR1.17 (P03)
SW21R: SW13.2, YJR1.18 (P04)
SW22R: SW21.2, YJR1.19 (P05)
SW23R: SW29.2, YJR1.20 (P06)
SW24R: SW36.2, YJR1.21 (P07)
SW30R: SW7.2, YJR1.14 (P00)
SW31R: SW14.2, YJR1.15 (P01)
SW32R: SW22.2, YJR1.16 (P02)
VCC_3.3V: PROGR1.4, R4.2, R5.2, REG1.2 (VO), YJR1.12 (VCC)
VCC_5V: AVR1.21 (VCC), C1.1, R2.1, R3.1, REG1.3 (VI), TP1.1 (VCC)
reset: AVR1.22 (RST), RST1.1

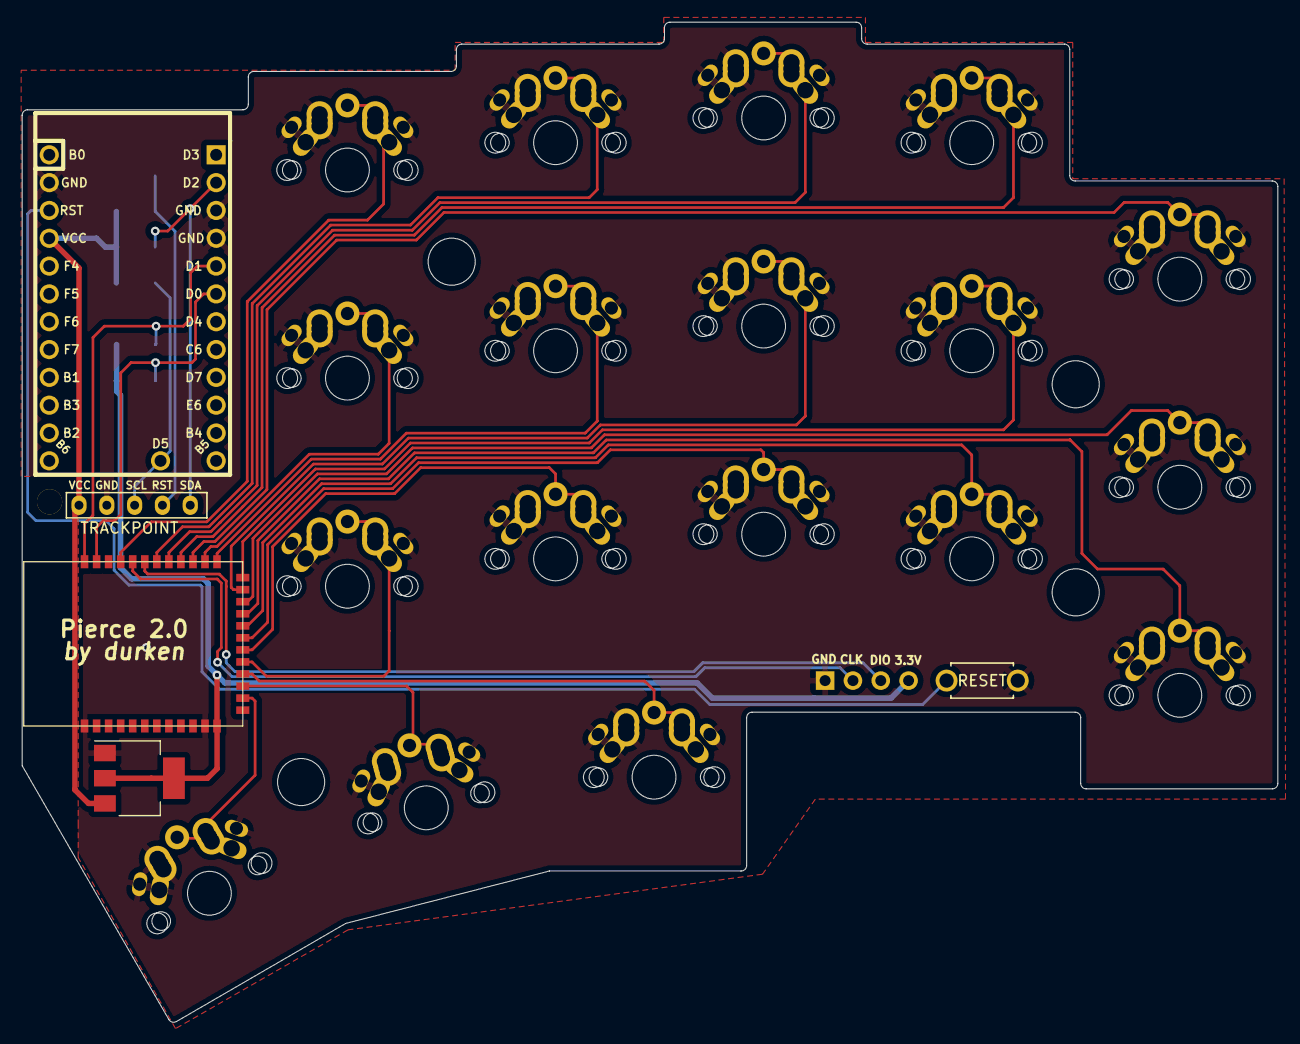
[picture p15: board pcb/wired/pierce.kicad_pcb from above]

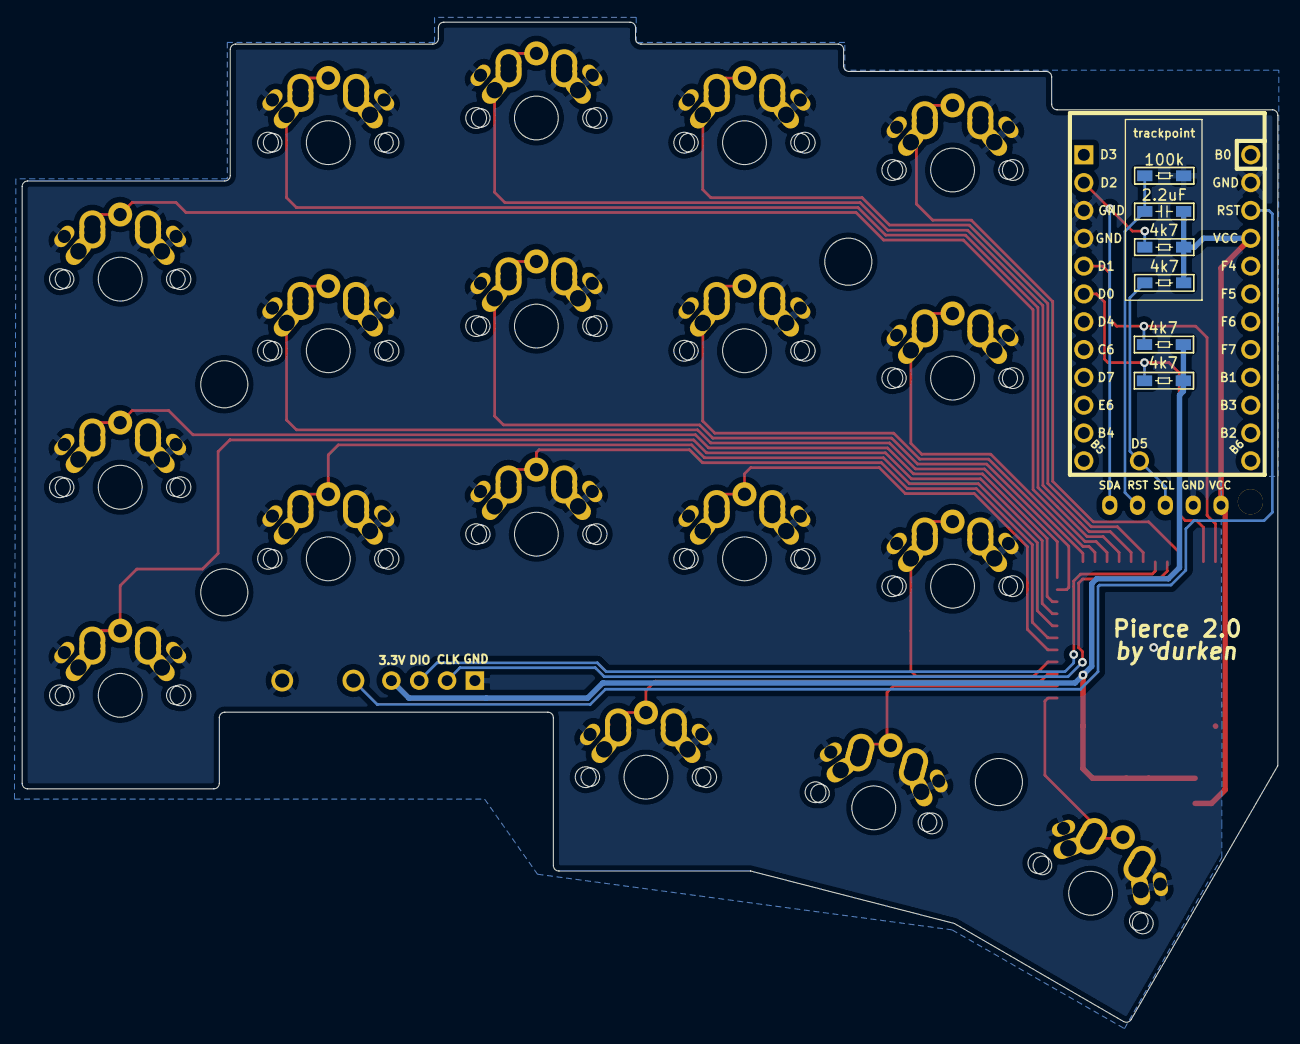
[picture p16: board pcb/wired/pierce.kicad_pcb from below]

Board: 2 copper layers, 114.6 x 91.3 mm, 35 parts (7 on the bottom side), 29 nets.

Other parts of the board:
Ref**: Val**; M2_HOLE_v2
Ref**#2, Ref**#3, Ref**#4: Val**; M2_HOLE_v2
Ref**#5: Val**; M2_Threads_v2

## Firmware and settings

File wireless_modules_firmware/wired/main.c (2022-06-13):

#include "host.h"
#include "nrf_gzll.h"
#include "nrf_drv_twi.h"
#include "nrf_gpio.h"

#define NRF_LOG_MODULE_NAME "APP"
#include "nrf_log.h"
#include "nrf_log_ctrl.h"

#define SLAVE_ADDR 0x20

#define TWI_INSTANCE_ID 0

static uint32_t data_payload_length = 4;
static uint8_t m_data_payload[NRF_GZLL_CONST_MAX_PAYLOAD_LENGTH];
static uint8_t matrix[8];
static uint8_t data[9];
static uint32_t input;

static const nrf_drv_twi_t m_twi = NRF_DRV_TWI_INSTANCE(TWI_INSTANCE_ID);

// Configure and initiate GPIO pins
static void gpio_init(void)
{
    nrf_gpio_cfg_input(R0C0, NRF_GPIO_PIN_PULLUP);
    nrf_gpio_cfg_input(R0C1, NRF_GPIO_PIN_PULLUP);
    nrf_gpio_cfg_input(R0C2, NRF_GPIO_PIN_PULLUP);
    nrf_gpio_cfg_input(R0C3, NRF_GPIO_PIN_PULLUP);
    nrf_gpio_cfg_input(R0C4, NRF_GPIO_PIN_PULLUP);

    nrf_gpio_cfg_input(R1C0, NRF_GPIO_PIN_PULLUP);
    nrf_gpio_cfg_input(R1C1, NRF_GPIO_PIN_PULLUP);
    nrf_gpio_cfg_input(R1C2, NRF_GPIO_PIN_PULLUP);
    nrf_gpio_cfg_input(R1C3, NRF_GPIO_PIN_PULLUP);
    nrf_gpio_cfg_input(R1C4, NRF_GPIO_PIN_PULLUP);

    nrf_gpio_cfg_input(R2C0, NRF_GPIO_PIN_PULLUP);
    nrf_gpio_cfg_input(R2C1, NRF_GPIO_PIN_PULLUP);
    nrf_gpio_cfg_input(R2C2, NRF_GPIO_PIN_PULLUP);
    nrf_gpio_cfg_input(R2C3, NRF_GPIO_PIN_PULLUP);
    nrf_gpio_cfg_input(R2C4, NRF_GPIO_PIN_PULLUP);

    nrf_gpio_cfg_input(R3C0, NRF_GPIO_PIN_PULLUP);
    nrf_gpio_cfg_input(R3C1, NRF_GPIO_PIN_PULLUP);
    nrf_gpio_cfg_input(R3C2, NRF_GPIO_PIN_PULLUP);
}

// Initiate TWI (I2C)
void twi_init(void)
{
    const nrf_drv_twi_config_t twi_config = {
        .scl = 19,
        .sda = 20,
        .frequency = NRF_TWI_FREQ_400K,
        .interrupt_priority = APP_IRQ_PRIORITY_HIGH,
        .clear_bus_init = false
    };

    nrf_drv_twi_init(&m_twi, &twi_config, NULL, NULL);

    nrf_drv_twi_enable(&m_twi);
}

// Scan the key matrix
static void matrix_scan()
{
    input = ~(NRF_GPIO->IN);

    matrix[4] = (((input >> R0C0) & 1) |
            (((input >> R0C1) & 1) << 1) |
            (((input >> R0C2) & 1) << 2) |
            (((input >> R0C3) & 1) << 3) |
            (((input >> R0C4) & 1) << 4)) &
        (0x1F);

    matrix[5] = (((input >> R1C0) & 1) |
            (((input >> R1C1) & 1) << 1) |
            (((input >> R1C2) & 1) << 2) |
            (((input >> R1C3) & 1) << 3) |
            (((input >> R1C4) & 1) << 4)) &
        (0x1F);

    matrix[6] = (((input >> R2C0) & 1) |
            (((input >> R2C1) & 1) << 1) |
            (((input >> R2C2) & 1) << 2) |
            (((input >> R2C3) & 1) << 3) |
            (((input >> R2C4) & 1) << 4)) &
        (0x1F);

    matrix[7] = (((input >> R3C0) & 1)  |
            (((input >> R3C1) & 1) << 1) |
            (((input >> R3C2) & 1) << 2)) &
        (0x1F);
}

// Send scanned matrix to pro micro (or equivalent)
void i2c_send_to_slave(void)
{
    data[0] = 0;
    for (int i = 0; i < 8; ++i)
    {
        data[i+1] = matrix[i];
    }
    nrf_drv_twi_tx(&m_twi, 0x20U, data, 9, false);
}

// Recieve data from device and save to local matrix array
void nrf_gzll_host_rx_data_ready(uint32_t pipe, nrf_gzll_host_rx_info_t rx_info)
{
    nrf_gzll_fetch_packet_from_rx_fifo(pipe, m_data_payload, &data_payload_length);

    if (data_payload_length > 0)
    {
        if (pipe == 0)
        {
            for(uint8_t i = 0;i < data_payload_length; ++i)
            {
                matrix[i] = m_data_payload[i];
            }
        }

        else
        {
            for(uint8_t i = 0;i < data_payload_length; ++i)
            {
                matrix[i+4] = m_data_payload[i];
            }
        }
    }
}

// Initiate and enable TWI, gazell and start sending matrix over TWI
int main(void)
{
    gpio_init();
    twi_init();
    nrf_gzll_init(NRF_GZLL_MODE_HOST);

    nrf_gzll_enable();

    while(true)
    {
        matrix_scan();
        i2c_send_to_slave();
    }
}

// Empty required callbacks
void nrf_gzll_device_tx_success(uint32_t pipe, nrf_gzll_device_tx_info_t tx_info)
{
}

void nrf_gzll_device_tx_failed(uint32_t pipe, nrf_gzll_device_tx_info_t tx_info)
{
}

void nrf_gzll_disabled()
{
}

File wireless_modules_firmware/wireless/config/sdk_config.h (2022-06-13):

#ifndef SDK_CONFIG_H
#define SDK_CONFIG_H
// <<< Use Configuration Wizard in Context Menu >>>\n
#ifdef USE_APP_CONFIG
#include "app_config.h"
#endif
// <h> nRF_Drivers 

// <e> RTC_ENABLED - nrf_drv_rtc - RTC peripheral driver
//==========================================================
#ifndef RTC_ENABLED
#define RTC_ENABLED 1
#endif
#if  RTC_ENABLED
// <o> RTC_DEFAULT_CONFIG_FREQUENCY - Frequency  <16-32768> 


#ifndef RTC_DEFAULT_CONFIG_FREQUENCY
#define RTC_DEFAULT_CONFIG_FREQUENCY 1000
#endif

// <q> RTC_DEFAULT_CONFIG_RELIABLE  - Ensures safe compare event triggering
 

#ifndef RTC_DEFAULT_CONFIG_RELIABLE
#define RTC_DEFAULT_CONFIG_RELIABLE 0
#endif

// <o> RTC_DEFAULT_CONFIG_IRQ_PRIORITY  - Interrupt priority
 

// <i> Priorities 0,2 (nRF51) and 0,1,4,5 (nRF52) are reserved for SoftDevice
// <0=> 0 (highest) 
// <1=> 1 
// <2=> 2 
// <3=> 3 

#ifndef RTC_DEFAULT_CONFIG_IRQ_PRIORITY
#define RTC_DEFAULT_CONFIG_IRQ_PRIORITY 3
#endif

// <q> RTC0_ENABLED  - Enable RTC0 instance
 

#ifndef RTC0_ENABLED
#define RTC0_ENABLED 1
#endif

// <q> RTC1_ENABLED  - Enable RTC1 instance
 

#ifndef RTC1_ENABLED
#define RTC1_ENABLED 0
#endif

// <q> RTC2_ENABLED  - Enable RTC2 instance
 

#ifndef RTC2_ENABLED
#define RTC2_ENABLED 0
#endif

// <o> NRF_MAXIMUM_LATENCY_US - Maximum possible time[us] in highest priority interrupt 
#ifndef NRF_MAXIMUM_LATENCY_US
#define NRF_MAXIMUM_LATENCY_US 2000
#endif

#endif //RTC_ENABLED
// </e>
// <e> CLOCK_ENABLED - nrf_drv_clock - CLOCK peripheral driver
//==========================================================
#ifndef CLOCK_ENABLED
#define CLOCK_ENABLED 1
#endif
#if  CLOCK_ENABLED
// <o> CLOCK_CONFIG_XTAL_FREQ  - HF XTAL Frequency
 
// <0=> Default (64 MHz) 
// <255=> Default (16 MHz) 
// <0=> 32 MHz 

#ifndef CLOCK_CONFIG_XTAL_FREQ
#define CLOCK_CONFIG_XTAL_FREQ 255
#endif

// <o> CLOCK_CONFIG_LF_SRC  - LF Clock Source
 
// <0=> RC 
// <1=> XTAL 
// <2=> Synth 

#ifndef CLOCK_CONFIG_LF_SRC
#define CLOCK_CONFIG_LF_SRC 1
#endif

// <o> CLOCK_CONFIG_IRQ_PRIORITY  - Interrupt priority
 

// <i> Priorities 0,2 (nRF51) and 0,1,4,5 (nRF52) are reserved for SoftDevice
// <0=> 0 (highest) 
// <1=> 1 
// <2=> 2 
// <3=> 3 

#ifndef CLOCK_CONFIG_IRQ_PRIORITY
#define CLOCK_CONFIG_IRQ_PRIORITY 3
#endif

#endif //CLOCK_ENABLED

// <e> PERIPHERAL_RESOURCE_SHARING_ENABLED - nrf_drv_common - Peripheral drivers common module
//==========================================================
#ifndef PERIPHERAL_RESOURCE_SHARING_ENABLED
#define PERIPHERAL_RESOURCE_SHARING_ENABLED 0
#endif
#if  PERIPHERAL_RESOURCE_SHARING_ENABLED
// <e> COMMON_CONFIG_LOG_ENABLED - Enables logging in the module.
//==========================================================
#ifndef COMMON_CONFIG_LOG_ENABLED
#define COMMON_CONFIG_LOG_ENABLED 0
#endif
#if  COMMON_CONFIG_LOG_ENABLED
// <o> COMMON_CONFIG_LOG_LEVEL  - Default Severity level
 
// <0=> Off 
// <1=> Error 
// <2=> Warning 
// <3=> Info 
// <4=> Debug 

#ifndef COMMON_CONFIG_LOG_LEVEL
#define COMMON_CONFIG_LOG_LEVEL 3
#endif

// <o> COMMON_CONFIG_INFO_COLOR  - ANSI escape code prefix.
 
// <0=> Default 
// <1=> Black 
// <2=> Red 
// <3=> Green 
// <4=> Yellow 
// <5=> Blue 
// <6=> Magenta 
// <7=> Cyan 
// <8=> White 

#ifndef COMMON_CONFIG_INFO_COLOR
#define COMMON_CONFIG_INFO_COLOR 0
#endif

// <o> COMMON_CONFIG_DEBUG_COLOR  - ANSI escape code prefix.
 
// <0=> Default 
// <1=> Black 
// <2=> Red 
// <3=> Green 
// <4=> Yellow 
// <5=> Blue 
// <6=> Magenta 
// <7=> Cyan 
// <8=> White 

#ifndef COMMON_CONFIG_DEBUG_COLOR
#define COMMON_CONFIG_DEBUG_COLOR 0
#endif

#endif //COMMON_CONFIG_LOG_ENABLED
// </e>

#endif //PERIPHERAL_RESOURCE_SHARING_ENABLED
// </e>
//==========================================================

// <h> nRF_Libraries 

//==========================================================
// <e> APP_TIMER_ENABLED - app_timer - Application timer functionality
//==========================================================
#ifndef APP_TIMER_ENABLED
#define APP_TIMER_ENABLED 1
#endif
#if  APP_TIMER_ENABLED
// <q> APP_TIMER_WITH_PROFILER  - Enable app_timer profiling
 

#ifndef APP_TIMER_WITH_PROFILER
#define APP_TIMER_WITH_PROFILER 0
#endif

// <q> APP_TIMER_KEEPS_RTC_ACTIVE  - Enable RTC always on
 

// <i> If option is enabled RTC is kept running even if there is no active timers.
// <i> This option can be used when app_timer is used for timestamping.

#ifndef APP_TIMER_KEEPS_RTC_ACTIVE
#define APP_TIMER_KEEPS_RTC_ACTIVE 0
#endif

#endif //APP_TIMER_ENABLED
// </e>

// <q> BUTTON_ENABLED  - app_button - buttons handling module
 

#ifndef BUTTON_ENABLED
#define BUTTON_ENABLED 1
#endif

// </h> 
//==========================================================

// <h> nRF_Log
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

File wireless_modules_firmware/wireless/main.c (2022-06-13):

#include "pierce.h"
#include "nrf_gzll.h"
#include "nrf_gpio.h"
#include "nrf_delay.h"
#include "nrf_drv_clock.h"
#include "nrf_drv_rtc.h"

// Set RTC instance
const nrf_drv_rtc_t rtc = NRF_DRV_RTC_INSTANCE(0); 

// Frequency of RTC = 32.768 / (RTC_PRESCALER + 1)
#define RTC_PRESCALER 32 // 32 -> RTC frequency ~ 1kHz

// Number of inactive ticks before going to deep sleep
#define INACTIVITY_THRESHOLD 500 // 0.5sec with 1kHz RTC

// Maximum number of transmission attempts
#define MAX_TX_ATTEMPTS         100 

static uint32_t input;
static uint8_t matrix[ROWS] = {0, 0, 0, 0};

// Configure and initiate GPIO pins
static void gpio_init(void)
{
    nrf_gpio_cfg_sense_input(R0C0, NRF_GPIO_PIN_PULLUP, NRF_GPIO_PIN_SENSE_LOW);
    nrf_gpio_cfg_sense_input(R0C1, NRF_GPIO_PIN_PULLUP, NRF_GPIO_PIN_SENSE_LOW);
    nrf_gpio_cfg_sense_input(R0C2, NRF_GPIO_PIN_PULLUP, NRF_GPIO_PIN_SENSE_LOW);
    nrf_gpio_cfg_sense_input(R0C3, NRF_GPIO_PIN_PULLUP, NRF_GPIO_PIN_SENSE_LOW);
    nrf_gpio_cfg_sense_input(R0C4, NRF_GPIO_PIN_PULLUP, NRF_GPIO_PIN_SENSE_LOW);

    nrf_gpio_cfg_sense_input(R1C0, NRF_GPIO_PIN_PULLUP, NRF_GPIO_PIN_SENSE_LOW);
    nrf_gpio_cfg_sense_input(R1C1, NRF_GPIO_PIN_PULLUP, NRF_GPIO_PIN_SENSE_LOW);
    nrf_gpio_cfg_sense_input(R1C2, NRF_GPIO_PIN_PULLUP, NRF_GPIO_PIN_SENSE_LOW);
    nrf_gpio_cfg_sense_input(R1C3, NRF_GPIO_PIN_PULLUP, NRF_GPIO_PIN_SENSE_LOW);
    nrf_gpio_cfg_sense_input(R1C4, NRF_GPIO_PIN_PULLUP, NRF_GPIO_PIN_SENSE_LOW);

    nrf_gpio_cfg_sense_input(R2C0, NRF_GPIO_PIN_PULLUP, NRF_GPIO_PIN_SENSE_LOW);
    nrf_gpio_cfg_sense_input(R2C1, NRF_GPIO_PIN_PULLUP, NRF_GPIO_PIN_SENSE_LOW);
    nrf_gpio_cfg_sense_input(R2C2, NRF_GPIO_PIN_PULLUP, NRF_GPIO_PIN_SENSE_LOW);
    nrf_gpio_cfg_sense_input(R2C3, NRF_GPIO_PIN_PULLUP, NRF_GPIO_PIN_SENSE_LOW);
    nrf_gpio_cfg_sense_input(R2C4, NRF_GPIO_PIN_PULLUP, NRF_GPIO_PIN_SENSE_LOW);

    nrf_gpio_cfg_sense_input(R3C2, NRF_GPIO_PIN_PULLUP, NRF_GPIO_PIN_SENSE_LOW);
    nrf_gpio_cfg_sense_input(R3C3, NRF_GPIO_PIN_PULLUP, NRF_GPIO_PIN_SENSE_LOW);
    nrf_gpio_cfg_sense_input(R3C4, NRF_GPIO_PIN_PULLUP, NRF_GPIO_PIN_SENSE_LOW);
}

// Scan the key matrix
static void matrix_scan(uint8_t *matrix)
{
    input = ~(NRF_GPIO->IN);

#ifdef RIGHT
    matrix[0] = (((input >> R0C4) & 1) |
            (((input >> R0C3) & 1) << 1) |
            (((input >> R0C2) & 1) << 2) |
            (((input >> R0C1) & 1) << 3) |
            (((input >> R0C0) & 1) << 4)) &
        (0x1F);

    matrix[1] = (((input >> R1C4) & 1) |
            (((input >> R1C3) & 1) << 1) |
            (((input >> R1C2) & 1) << 2) |
            (((input >> R1C1) & 1) << 3) |
            (((input >> R1C0) & 1) << 4)) &
        (0x1F);

    matrix[2] = (((input >> R2C4) & 1) |
            (((input >> R2C3) & 1) << 1) |
            (((input >> R2C2) & 1) << 2) |
            (((input >> R2C1) & 1) << 3) |
            (((input >> R2C0) & 1) << 4)) &
        (0x1F);

    matrix[3] = (((input >> R3C4) & 1)  |
            (((input >> R3C3) & 1) << 1) |
            (((input >> R3C2) & 1) << 2)) &
        (0x1F);

#else
    matrix[0] = (((input >> R0C0) & 1) |
            (((input >> R0C1) & 1) << 1) |
            (((input >> R0C2) & 1) << 2) |
            (((input >> R0C3) & 1) << 3) |
            (((input >> R0C4) & 1) << 4)) &
        (0x1F);

    matrix[1] = (((input >> R1C0) & 1) |
            (((input >> R1C1) & 1) << 1) |
            (((input >> R1C2) & 1) << 2) |
            (((input >> R1C3) & 1) << 3) |
            (((input >> R1C4) & 1) << 4)) &
        (0x1F);

    matrix[2] = (((input >> R2C0) & 1) |
            (((input >> R2C1) & 1) << 1) |
            (((input >> R2C2) & 1) << 2) |
            (((input >> R2C3) & 1) << 3) |
            (((input >> R2C4) & 1) << 4)) &
        (0x1F);

    matrix[3] = ((((input >> R3C2) & 1) << 2) |
            (((input >> R3C3) & 1) << 3) |
            (((input >> R3C4) & 1) << 4)) &
        (0x1F);
#endif
}

// Check if no keys are pressed
static bool empty_matrix(const uint8_t* matrix)
{
    for(int i=0; i < ROWS; i++)
    {
        if (matrix[i])
        {
            return false;
        }
    }
    return true;
}

// Send the matrix status to host
void matrix_send(uint8_t *matrix)
{   
    nrf_gzll_add_packet_to_tx_fifo(PIPE_NUMBER, matrix, ROWS);
}

// Set MCU to go to deep sleep after set number of ticks with no keypresses 
static void handle_inactivity(const uint8_t *matrix)
{
    static uint32_t inactivity_ticks = 0;

    if (empty_matrix(matrix)) {
        inactivity_ticks++;
        if (inactivity_ticks > INACTIVITY_THRESHOLD) {
            nrf_drv_rtc_disable(&rtc);
            inactivity_ticks = 0;

            NRF_POWER->SYSTEMOFF = 1;
        }
    } else {
        inactivity_ticks = 0;
    }
}

// Do this every clock tick
static void tick(nrf_drv_rtc_int_type_t int_type)
{
    matrix_scan(matrix);

    handle_inactivity(matrix);

    matrix_send(matrix);
}

// RTC peripheral configuration
static void rtc_config(void)
{
    nrf_drv_rtc_config_t config = NRF_DRV_RTC_DEFAULT_CONFIG;
    config.prescaler = 32;
    nrf_drv_rtc_init(&rtc, &config, tick);

    nrf_drv_rtc_tick_enable(&rtc,true);

    nrf_drv_rtc_enable(&rtc);
}

// Low frequency clock configuration
static void lfclk_config(void)
{
    nrf_drv_clock_init();

    nrf_drv_clock_lfclk_request(NULL);
}

// Initiate and configure everything, then go to sleep and wait for clock tick interrupt
int main()
{
    gpio_init();
    lfclk_config();
    rtc_config();

    nrf_gzll_init(NRF_GZLL_MODE_DEVICE);
    nrf_gzll_set_max_tx_attempts(MAX_TX_ATTEMPTS);

    nrf_gzll_enable();
    while (1)
    {
        __SEV();
        __WFE();
        __WFE();
    }
}

// Unused callbacks
void nrf_gzll_host_rx_data_ready(uint32_t pipe, nrf_gzll_host_rx_info_t rx_info)
{
}


void nrf_gzll_disabled()
{
}

void  nrf_gzll_device_tx_success(uint32_t pipe, nrf_gzll_device_tx_info_t tx_info)
{
}

void nrf_gzll_device_tx_failed(uint32_t pipe, nrf_gzll_device_tx_info_t tx_info)
{
}

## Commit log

2021-02-13 v 0.2
    [pierce.kicad_pcb]
2021-02-14 Routed right half
    [pierce.kicad_pcb]
2021-02-15 Finished routing (improved routing from last commit)
    [pierce.kicad_pcb, pierce.sch]
2021-02-17 Adjusted text on silk layer
    [pierce.kicad_pcb]
2021-02-17 moved pcb files to pcb folder
    [pierce.kicad_pcb, pierce.sch]
2021-02-17 added pcb.png
2021-02-18 Changed footprint to Elite-C (Reversed for flipped mounting) Changed pins connected to trackpoint to allow USART. (CLK-D5, SDA-D2) Rearranged connection order of trackpoint to match R61 module Cleane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
    [pierce.sch]
2021-02-18 added back missing mounting holes
    [pierce.kicad_pcb]
2021-02-22 added plate hole footprint
2021-02-24 added silk text
    [pierce.kicad_pcb]
2021-02-24 add connection for rotary encoder
    [pierce.kicad_pcb, pierce.sch]
2021-02-24 small adjustments
    [pierce.kicad_pcb]
2021-02-24 locked mounting holes
    [pierce.kicad_pcb]
2021-02-28 changed switch footprint to support alps switcher
    [pierce.kicad_pcb]
2021-03-03 adjust edgecut. add breakaway tabs
    [pierce.kicad_pcb]
2021-03-04 add seperate pcbs for left/right.
    [pierce-1.1-left.kicad_pcb, pierce-1.1-right.kicad_pcb, pierce.kicad_pcb]
2021-03-17 change pro micro footprint, smaller drill holes
    [pierce.kicad_pcb]
2021-03-24 add case STLs
    [pierce-case-left.stl, pierce-case-right_tracpoint.stl, pierce-plate-left.stl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]
2021-06-15 update readme with BOM
2021-06-16 add gerber files
2021-06-16 small schematics cleanup
    [pierce.sch]
2021-06-16 pcb files cleanup
    [pierce-1.1-left.kicad_pcb, pierce-1.1-right.kicad_pcb]
2021-06-17 adjust schematics for wireless connection between halves
    [pierce.kicad_pcb, pierce.sch]
2021-06-17 adjust schematics with i2c connecion to elite-c
    [pierce.sch]
2021-06-18 place and route 2.0
    [pierce.kicad_pcb, pierce.sch]
2021-06-21 change footprint to make wireless side reversible
    [pierce.kicad_pcb, pierce.sch]
2021-06-21 add reciever pcb for dual wireless setup
    [pierce.kicad_pcb, pierce.sch]
2021-06-21 rearrange folder structure
    [pierce-case-left.stl, pierce-case-right_tracpoint.stl, pierce-plate-left.stl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]
2021-06-21 add pcb pics
2021-06-22 add gnd planes
    [pierce.kicad_pcb, pierce.sch]
2021-06-22 small visual adjustments
    [pierce.kicad_pcb]
2021-06-23 small pcb adjustments
    [pierce.kicad_pcb]
2022-03-18 prototype - ordered
    [pierce-B_Cu.gbl, pierce-B_Mask.gbs, pierce-B_Paste.gbp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]
2022-05-11 cleanup, add wireless_modules_firmware
    [pierce-case-left.stl, pierce-case-right_tracpoint.stl, pierce-plate-left.stl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]
2022-05-21 add some plates for 3d printing
    [alps_plate.3mf, wired_trackpoint_screwless.3mf, wireless_bottom_screwless.3mf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]
2022-09-06 Top and bottom plates for MX Cherry switches.
    Top and bottom plates for MX Cherry switches.
    They are not ideal, there are room for improvement.
    Have a nice day.
    [20220710.DURKEN1.PIERCE.01.stl, 20220712.DURKEN1.PIERCE.00.stl]
2022-10-12 Delete 20220712.DURKEN1.PIERCE.00.stl
    Can't find another way to rename.
    [20220712.DURKEN1.PIERCE.00.stl]
2022-10-12 Delete 20220710.DURKEN1.PIERCE.01.stl
    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
    [20220710.DURKEN1.PIERCE.01.stl]
2022-10-12 Add files via upload
    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
    [Pierce MX Bottom Plate.stl, Pierce MX Top Plate.stl]
2024-09-14 add reciever box stl files. thanks @tokyo2006
    [receiver_bottom.stl, receiver_top.stl]
